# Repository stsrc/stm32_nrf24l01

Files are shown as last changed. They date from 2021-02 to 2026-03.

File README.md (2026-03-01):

# stm32_nrf24l01 - GPS localization project

Idea of this project is to create GPS localization system which utilises android
application to present distance and direction to the GPS receiver.

To achieve that multiple devices are used: on slave side we use NEO-6M GPS
module and nrf24l01 module to transmit GPS data to the master side.
On master side we use nrf24l01 to receive GPS data and HM-10 module to send it
to the android phone.

Android application is located in another repository: [whereIsCat](https://github.com/stsrc/whereIsCat)

## Repository content:

slave PCB with nrf24l01 transmitter and NEO-6M GPS receiver, battery powered

    ./src-kicad/stm32_slave_bat

slave firmware

    ./stm32f031f6_slave

master PCB with nrf24l01 receiver and HM-10 bluetooth transmitter, battery powered

    ./src-kicad/stm32_master_bt_bat

master firmware

    ./stm32f031f6_master

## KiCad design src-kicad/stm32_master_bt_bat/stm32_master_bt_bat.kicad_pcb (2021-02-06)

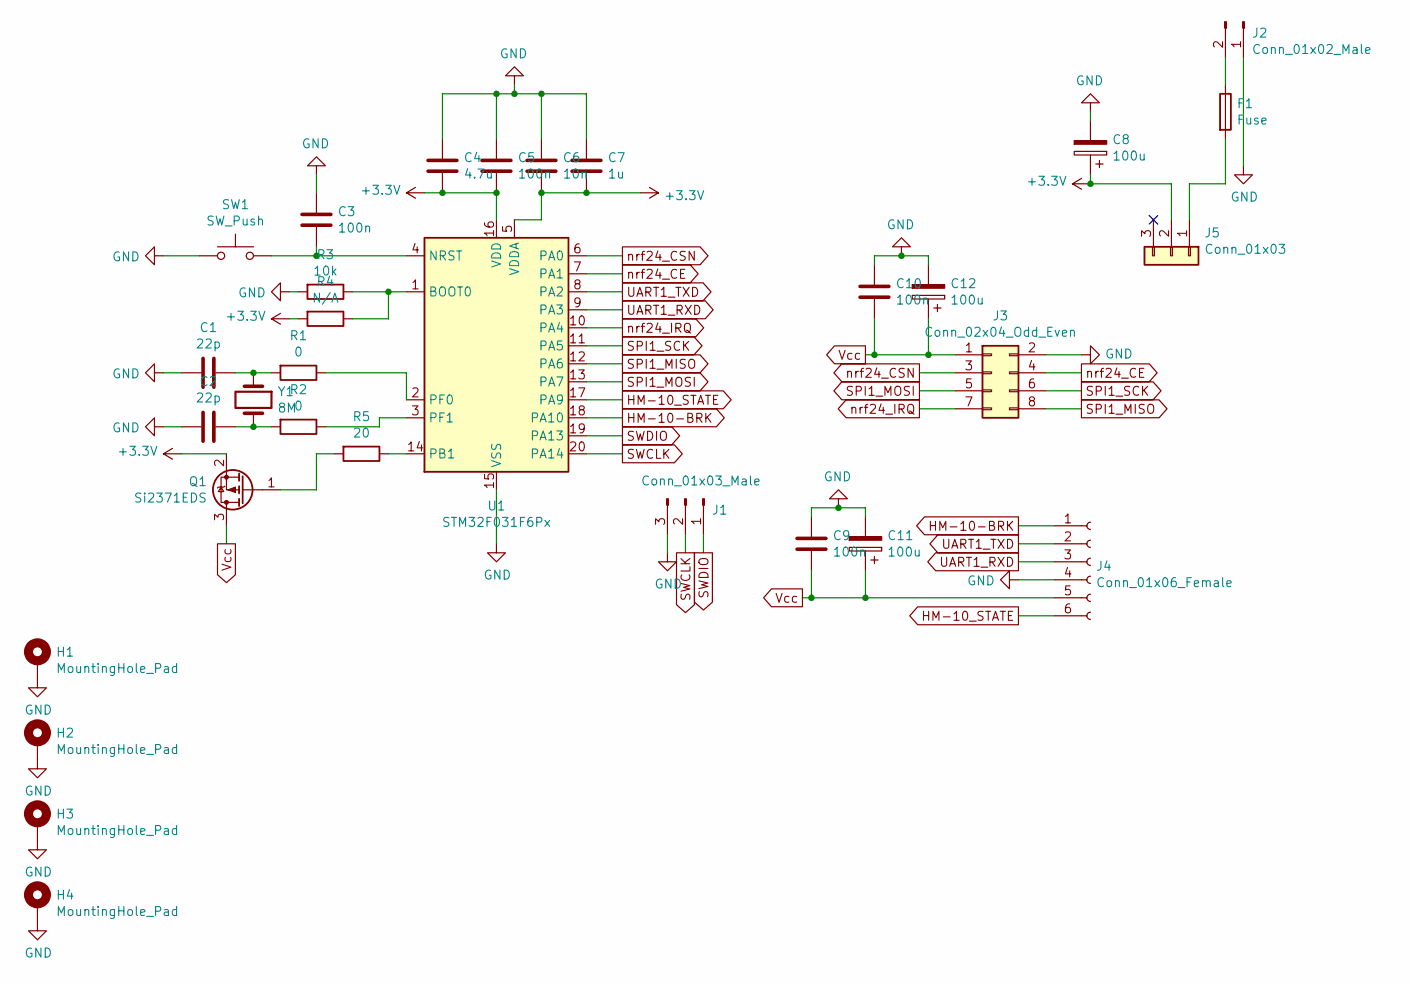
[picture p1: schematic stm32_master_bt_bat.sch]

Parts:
C1, C2: 22p; C_0805_2012Metric_Pad1.18x1.45mm_HandSolder
C3, C5, C9, C10: 100n; C_0805_2012Metric_Pad1.18x1.45mm_HandSolder
C4: 4.7u; C_0805_2012Metric_Pad1.18x1.45mm_HandSolder
C6: 10n; C_0805_2012Metric_Pad1.18x1.45mm_HandSolder
C7: 1u; C_0805_2012Metric_Pad1.18x1.45mm_HandSolder
C8, C11, C12: 100u; CP_Elec_6.3x5.8
F1: Fuse; smd-2410
H1, H2, H3, H4: MountingHole_Pad; MountingHole_3.2mm_M3_DIN965_Pad
J1: Conn_01x03_Male; PinHeader_1x03_P2.54mm_Vertical
J2: Conn_01x02_Male; PinHeader_1x02_P2.54mm_Vertical
J3: Conn_02x04_Odd_Even; PinSocket_2x04_P2.54mm_Vertical
J4: Conn_01x06_Female; PinSocket_1x06_P2.54mm_Vertical
J5: Conn_01x03; PRZELBL1X3
Q1: Si2371EDS; SOT-23
R1, R2: 0; R_0805_2012Metric_Pad1.20x1.40mm_HandSolder
R3: 10k; R_0805_2012Metric_Pad1.20x1.40mm_HandSolder
R4: N/A; R_0805_2012Metric_Pad1.20x1.40mm_HandSolder
R5: 20; R_0805_2012Metric_Pad1.20x1.40mm_HandSolder
SW1: SW_Push; SW_PUSH_6mm_H5mm
U1: STM32F031F6Px; TSSOP-20_4.4x6.5mm_P0.65mm
Y1: 8M; Crystal_SMD_HC49-SD

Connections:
+3V3: C4.2, C5.2, C6.1, C7.1, C8.1, J5.2, Q1.2 (S), R4.2, U1.5 (VDDA), U1.16 (VDD)
GND: C1.2, C2.2, C3.1, C4.1, C5.1, C6.2, C7.2, C8.2, C9.1, C10.1, C11.2, C12.2, H1.1, H2.1, H3.1, H4.1, J1.3, J2.1, J3.2, J4.4, R3.2, SW1.1, U1.15 (VSS)
HM-10-BRK: J4.1, U1.18 (PA10)
HM-10_STATE: J4.6, U1.17 (PA9)
unnamed: C1.1, R1.2, Y1.1
unnamed: C2.1, R2.2, Y1.2
unnamed: C3.2, SW1.2, U1.4 (NRST)
unnamed: F1.1, J2.2
unnamed: F1.2, J5.1
unnamed: Q1.1 (G), R5.2
unnamed: R1.1, U1.2 (PF0)
unnamed: R2.1, U1.3 (PF1)
unnamed: R3.1, R4.1, U1.1 (BOOT0)
unnamed: R5.1, U1.14 (PB1)
SPI1_MISO: J3.8, U1.12 (PA6)
SPI1_MOSI: J3.5, U1.13 (PA7)
SPI1_SCK: J3.6, U1.11 (PA5)
SWCLK: J1.2, U1.20 (PA14)
SWDIO: J1.1, U1.19 (PA13)
UART1_RXD: J4.3, U1.9 (PA3)
UART1_TXD: J4.2, U1.8 (PA2)
Vcc: C9.2, C10.2, C11.1, C12.1, J3.1, J4.5, Q1.3 (D)
nrf24_CE: J3.4, U1.7 (PA1)
nrf24_CSN: J3.3, U1.6 (PA0)
nrf24_IRQ: J3.7, U1.10 (PA4)

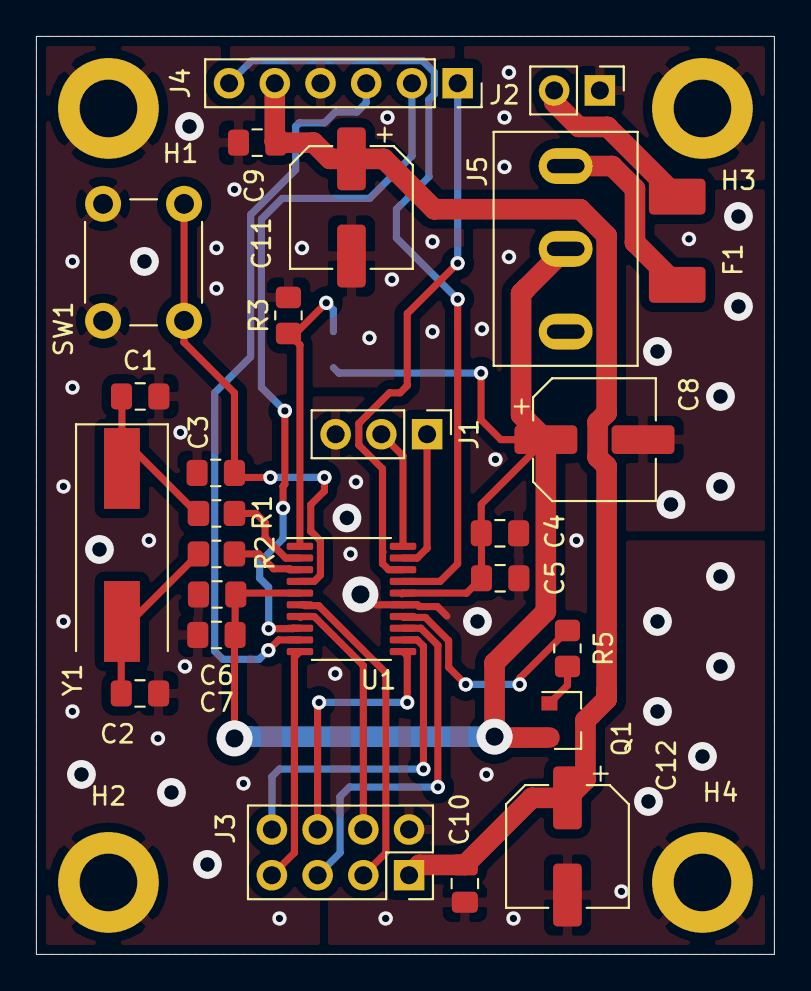
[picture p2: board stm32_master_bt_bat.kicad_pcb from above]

Board: 2 copper layers, 41.0 x 51.0 mm, 31 parts (1 on the bottom side), 25 nets.

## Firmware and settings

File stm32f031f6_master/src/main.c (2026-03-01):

/*
 * where-is-catiusha - cat localisation project
 * Copyright (C) 2021 Konrad Gotfryd
 *
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
 * You should have received a copy of the GNU General Public License
 * along with this program; if not, write to the Free Software
 * Foundation, Inc., 51 Franklin Street, Fifth Floor, Boston, MA  02110-1301, USA.
 */

#include <stm32f0xx.h>
#include <core_cm0.h>
#include <stm32f0xx_hal_gpio.h>
#include <string.h>
#include "NRF24.h"
#include "stupid_delay.h"
#include <stm32f0xx_hal.h>
#include "UART.h"

void clock_init(void)
{
	//HSE turn on
	RCC->CR |= RCC_CR_HSEON;
	while(!(RCC->CR & RCC_CR_HSERDY));

	// PLL input clock x6
	RCC->CFGR &= ~(0xF << 18);
	RCC->CFGR |= RCC_CFGR_PLLMUL6;

	// PLL source - HSE/PREDIV
	RCC->CFGR &= ~(0x3 << 15);
	RCC->CFGR |= RCC_CFGR_PLLSRC_HSE_PREDIV;

	//HSE divider for PLL input clock
	RCC->CFGR &= ~(1 << 17);

	//PREDIV input clock - no prediv
	RCC->CFGR2 &= ~(0b1111);

	//PLL turn on
	RCC->CR |= RCC_CR_PLLON;
	while(!(RCC->CR & RCC_CR_PLLRDY));

	// Use PLL
	RCC->CFGR &= ~(0b11);
	RCC->CFGR |= RCC_CFGR_SW_PLL;
	while(!(RCC->CFGR & RCC_CFGR_SWS_PLL));

	SystemCoreClock = 48000000;
}

int main(void){
	__HAL_RCC_GPIOA_CLK_ENABLE();
	__HAL_RCC_GPIOB_CLK_ENABLE();

	HAL_Init();

	clock_init();

	delay_init();
	UART_1_init();

	GPIO_InitTypeDef gpio = {
		.Pin = GPIO_PIN_1,
		.Mode = GPIO_MODE_OUTPUT_PP,
		.Speed = GPIO_SPEED_FREQ_HIGH,
		.Pull = GPIO_NOPULL,
		.Alternate = 0,
	};
	HAL_GPIO_Init(GPIOB, &gpio);
	HAL_GPIO_WritePin(GPIOB, GPIO_PIN_1, GPIO_PIN_SET);
	delay_ms(1000);
	HAL_GPIO_WritePin(GPIOB, GPIO_PIN_1, GPIO_PIN_RESET);
	delay_ms(1);

	struct nrf24 nrf = {
		.spi_handler = { 0 },
		.spi_instance = SPI1,
		.csn = GPIO_PIN_0,
		.ce = GPIO_PIN_1,
		.irq = GPIO_PIN_4,
		.gpio = GPIOA
	};
	NRF24_init(&nrf);
	NRF24_init_receiver(&nrf);
	delay_ms(2);

	while(1){
		uint8_t buffer[512];
		memset(buffer, 0, sizeof(buffer));
		if (!NRF24_receiver_receive(&nrf, buffer, sizeof(buffer))) {
			while(1);
		}
		size_t stringLength = strlen((char *) buffer);
		if (stringLength) {
			buffer_set_text(&UART1_transmit_buffer, (const char *) buffer, stringLength);
			UART_1_transmit();
		}
		delay_ms(10);
	}

	return 0;
}

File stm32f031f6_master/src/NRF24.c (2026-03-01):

/*
 * where-is-catiusha - cat localisation project
 * Copyright (C) 2021 Konrad Gotfryd
 *
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
 * You should have received a copy of the GNU General Public License
 * along with this program; if not, write to the Free Software
 * Foundation, Inc., 51 Franklin Street, Fifth Floor, Boston, MA  02110-1301, USA.
 */

#include "NRF24.h"
#include "UART.h"
#include <stdio.h>
#include <stdbool.h>
#include "stupid_delay.h"

void EXTI4_15_IRQHandler(void)
{
}

static HAL_StatusTypeDef NRF24_reg_read(struct nrf24 *nrf,
					uint8_t reg,
					uint8_t *data,
					uint8_t dataSize)
{
	HAL_StatusTypeDef ret;
	HAL_GPIO_WritePin(nrf->gpio, nrf->csn, GPIO_PIN_RESET);
	ret = SPI_send(&(nrf->spi_handler), &reg);
	if (ret)
		return ret;
	ret = SPI_read(&(nrf->spi_handler), data, dataSize);
	if (ret)
		return ret;
	ret = SPI_read(&(nrf->spi_handler), data, dataSize);
	if (ret)
		return ret;
	HAL_GPIO_WritePin(nrf->gpio, nrf->csn, GPIO_PIN_SET); //CSN
	return ret;
}

static HAL_StatusTypeDef NRF24_reg_write(struct nrf24 *nrf,
					 uint8_t reg,
					 uint8_t *data,
					 uint8_t dataSize)
{
	HAL_StatusTypeDef ret;
	HAL_GPIO_WritePin(nrf->gpio, nrf->csn, GPIO_PIN_RESET);
	uint8_t value = 0b00100000 | reg;
	ret = SPI_send(&(nrf->spi_handler), &value);
	if (ret) return ret;
	ret = SPI_send(&(nrf->spi_handler), data);
	if (ret) return ret;
	HAL_GPIO_WritePin(nrf->gpio, nrf->csn, GPIO_PIN_SET); //CSN
	return ret;
}

void NRF24_init(struct nrf24 *nrf)
{
	SPI_init(&(nrf->spi_handler), nrf->spi_instance);

	GPIO_InitTypeDef gpio =
	{
		.Pin = nrf->csn,
		.Mode = GPIO_MODE_OUTPUT_PP,
		.Speed = GPIO_SPEED_FREQ_HIGH,
		.Pull = GPIO_NOPULL,
		.Alternate = 0,
	};
	HAL_GPIO_Init(nrf->gpio, &gpio);

	gpio.Pin = nrf->ce;
	HAL_GPIO_Init(nrf->gpio, &gpio);

	if (nrf->irq) {
		gpio.Pin = nrf->irq;
		gpio.Mode = GPIO_MODE_IT_FALLING;
		HAL_GPIO_Init(nrf->gpio, &gpio);
		if (nrf->irq == GPIO_PIN_4) {
//			HAL_NVIC_EnableIRQ(EXTI4_15_IRQn);
		}
	}

	HAL_GPIO_WritePin(nrf->gpio, nrf->csn, GPIO_PIN_SET); //CSN
	delay_ms(100);
	HAL_GPIO_WritePin(nrf->gpio, nrf->ce, GPIO_PIN_SET); //CE
	delay_ms(100);
}

void NRF24_init_receiver(struct nrf24 *nrf)
{
	uint8_t value = 0x0b;
	NRF24_reg_write(nrf, 0x00, &value, 1);

	//set packet length to 1
	value = 1;
	NRF24_reg_write(nrf, 0x11, &value, 1);

	//set data rate to 250kbps and RF output power to 0dBm
	value = 0b00100110;
	NRF24_reg_write(nrf, 0x06, &value, 1);
}

bool NRF24_receiver_receive(struct nrf24 *nrf, uint8_t *buffer, size_t bufferSize)
{
	uint8_t status;
	NRF24_reg_read(nrf, 0x07, &status, 1);
	if (status & 0b01000000) {
		// got packet - check its size
		uint8_t readVal;
		uint8_t it = 0;
		uint8_t sizeOfMessage;
		uint8_t registerValue;
packet:
		NRF24_reg_read(nrf, 0x11, &sizeOfMessage, 1);

		if (it + sizeOfMessage > bufferSize)
			return false; //TODO: error logging

		// read packet
		readVal = 0b01100001;
		HAL_GPIO_WritePin(nrf->gpio, nrf->csn, GPIO_PIN_RESET);
		SPI_send(&(nrf->spi_handler), &readVal);
		SPI_read(&(nrf->spi_handler), &buffer[it], sizeOfMessage);
		it += sizeOfMessage;
		HAL_GPIO_WritePin(nrf->gpio, nrf->csn, GPIO_PIN_SET);

		//clear irq

		NRF24_reg_read(nrf, 0x07, &registerValue, 1);
		registerValue |= 0b01000000;
		NRF24_reg_write(nrf, 0x07, &registerValue, 1);

		//check if there is data
		NRF24_reg_read(nrf, 0x17, &registerValue, 1);
		if (!(registerValue & 0b00000001)) {
			goto packet;
		}
	}
	return true;
}

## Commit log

2020-12-19 Make SPI more generic
2020-12-20 it works, but fails at 2 first commands...
    [NRF24.c, SPI.c, main.c]
2020-12-21 Fix case with different sizeOfMessage
    [NRF24.c]
2020-12-30 add kicad project sources
    [my_backup-stm32_master.kicad_pcb, stm32_master.kicad_pcb, stm32_master.sch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]
2020-12-30 Change button shape
    [stm32_master_bt_bat.sch]
2020-12-31 Move stm32f100rb into seperate directory
2020-12-31 add stm32f031f6 directory
2020-12-31 Minor fixes in kicad
    [stm32_master_bt_bat.kicad_pcb, stm32_master_bt_bat.sch, stm32_slave_bat.kicad_pcb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]
2021-02-06 update src-kicad directory (all files)
    [stm32_master_bt_bat-B_Cu.gbr, stm32_master_bt_bat-B_Mask.gbr, stm32_master_bt_bat-B_SilkS.gbr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]
2021-02-13 Configure UART via registers not HAL function
2021-02-21 Temporary save of stm32f031f6_slave
2021-03-26 UART changes
2021-04-11 Add README.md. Remove old projects from src-kicad. Remove ignored code from stm32f031f6_master/src/NRF24.h
    [my_backup-stm32_master.kicad_pcb, stm32_master.kicad_pcb, stm32_master.sch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]
2026-03-01 Fix NRF24.c driver for slave device
    This commit fixes issue with one message being left on each loop
    iteration. It was caused by wrong order of setting/resseting csn and ce
    pins.
    Also delay_ms() were a little reworked.
    [NRF24.c]
2026-03-01 Refactor slave's SPI.c a little
2026-03-01 Simple refactor of master's SPI.c
2026-03-01 Remove stm32f100rb code
    This code was needed only at the beggining

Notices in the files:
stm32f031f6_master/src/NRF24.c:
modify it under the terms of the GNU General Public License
